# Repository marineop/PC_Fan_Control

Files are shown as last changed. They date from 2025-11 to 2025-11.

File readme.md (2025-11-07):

## Introduction
I have a PC fan that I removed from a CPU liquid cooler, and I'm powering it with a 12V power supply to use it for air filtration.  
However, when it's late at night, the fan's noise is a bit loud. But isn't this a PWM fan? I could use a development board to output a PWM signal and control the speed, but then I'd be short a development board.  
While searching online, I happened to come across a few useful online resources. I realized that in this day and age, this is actually possible to DIY a PCB board for simple device controls.  
* [Noctua PWM specifications white paper](https://cdn.noctua.at/media/Noctua_PWM_specifications_white_paper.pdf)
* [KiCad tutorial video from DigiKey](https://www.youtube.com/watch?v=vaCVh2SAZY4&list=PLEBQazB0HUyR24ckSZ5u05TZHV9khgA1O&index=1)
* [TI Power Dedigner](https://webench.ti.com/power-designer/)
* [OSH Park](https://oshpark.com/)
* [Mouser](https://www.mouser.com)

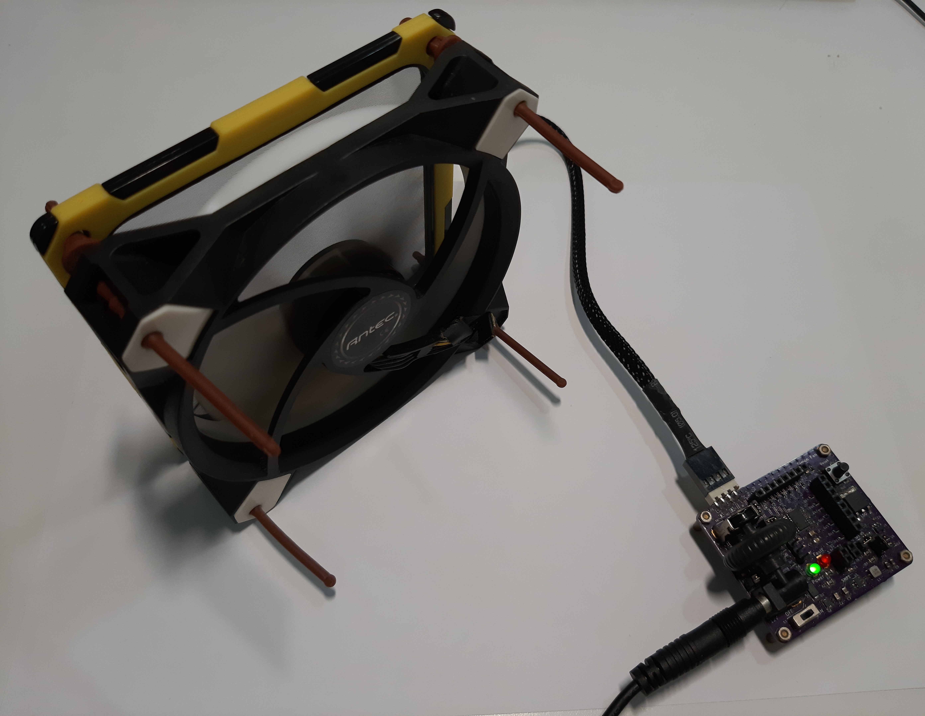
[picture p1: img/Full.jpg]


## Functionality

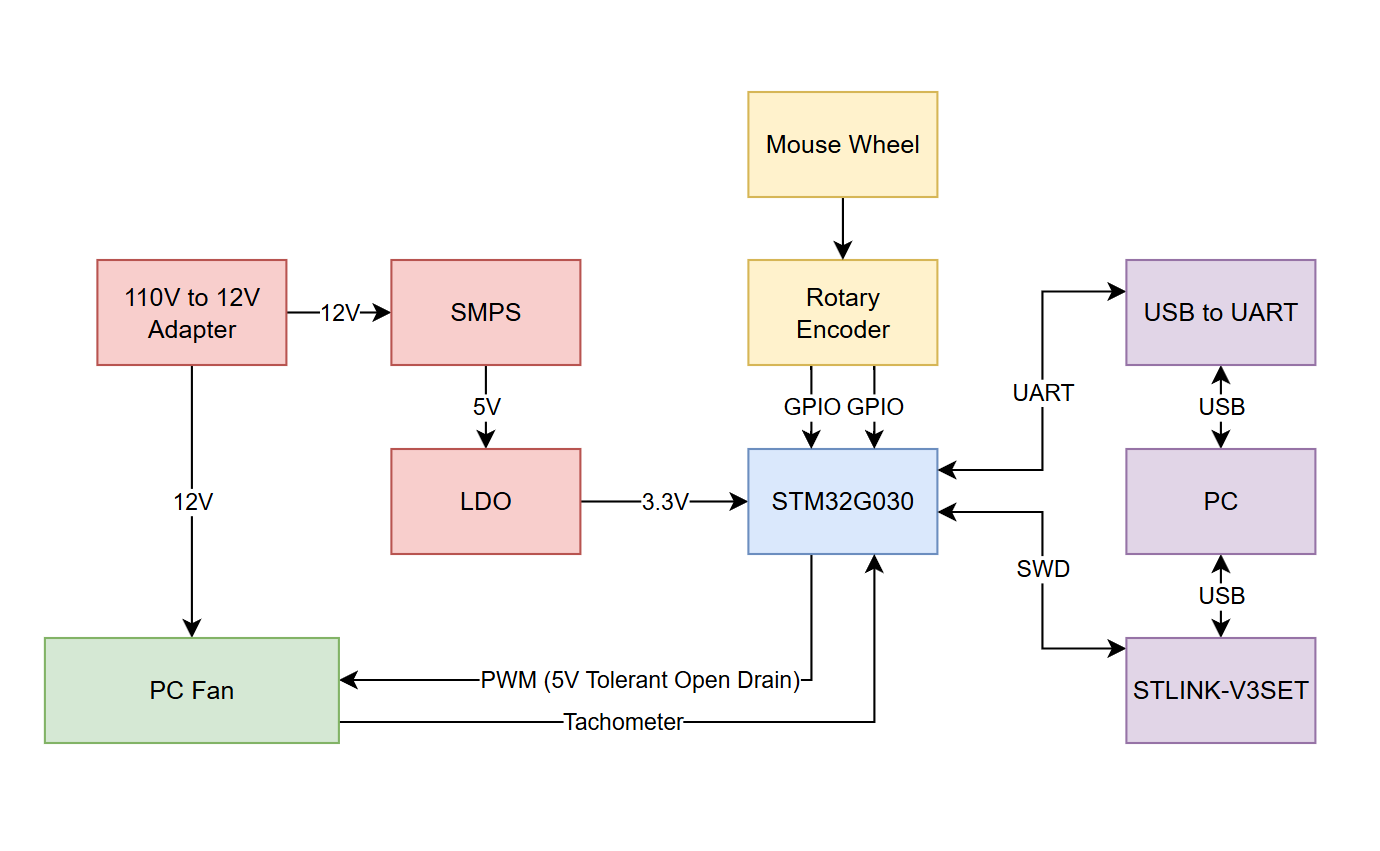
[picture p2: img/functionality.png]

## Schematic - KiCad, Ti Power Deisgner  
* [KiCad](https://www.kicad.org/)  
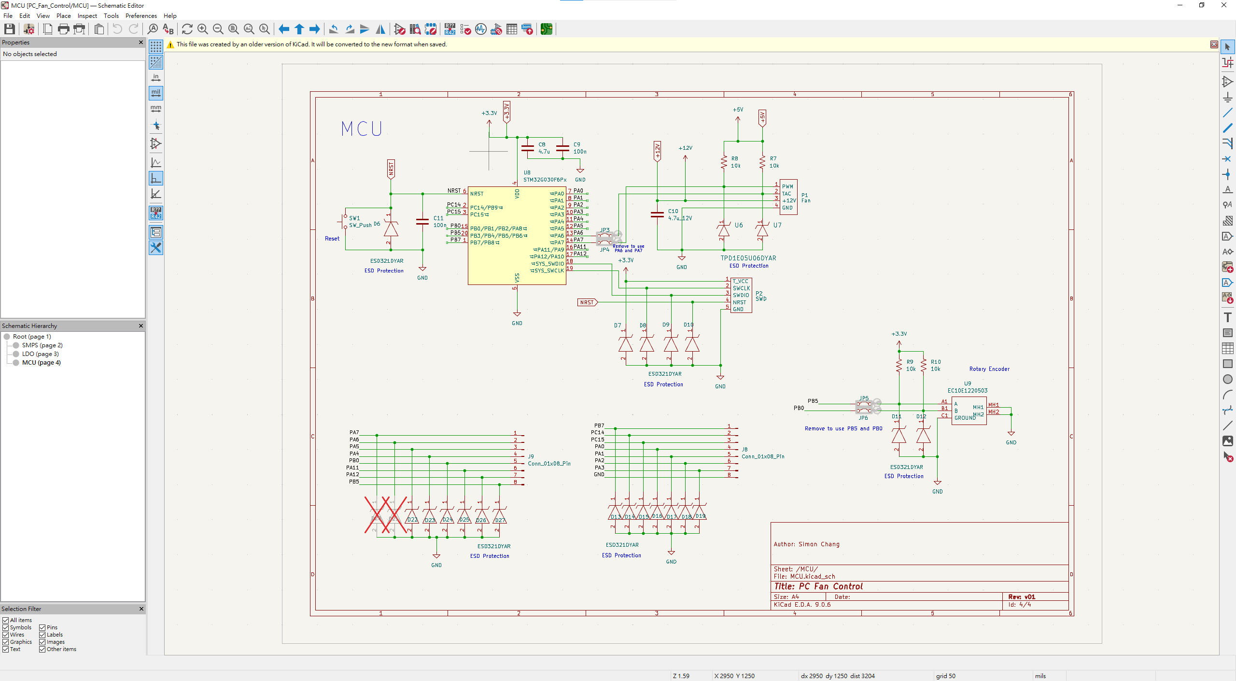
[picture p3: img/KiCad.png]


## PCB Layout - KiCad  
* Front side
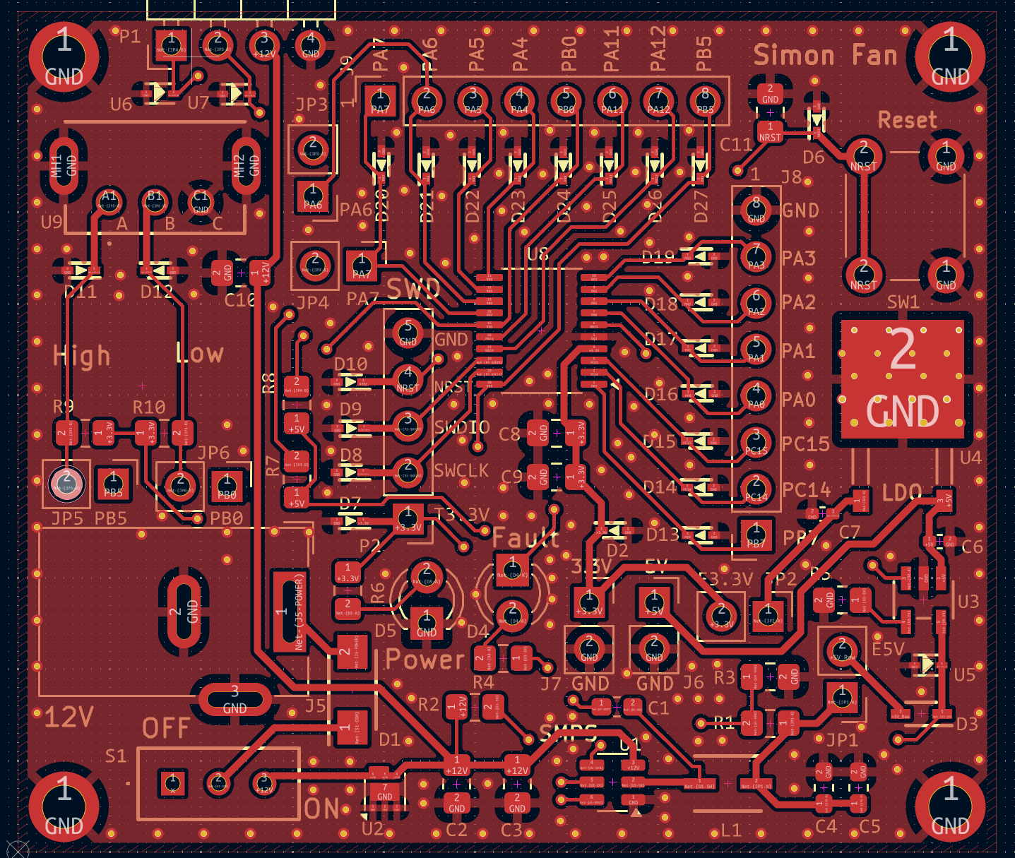
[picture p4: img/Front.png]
Front side

* Back side
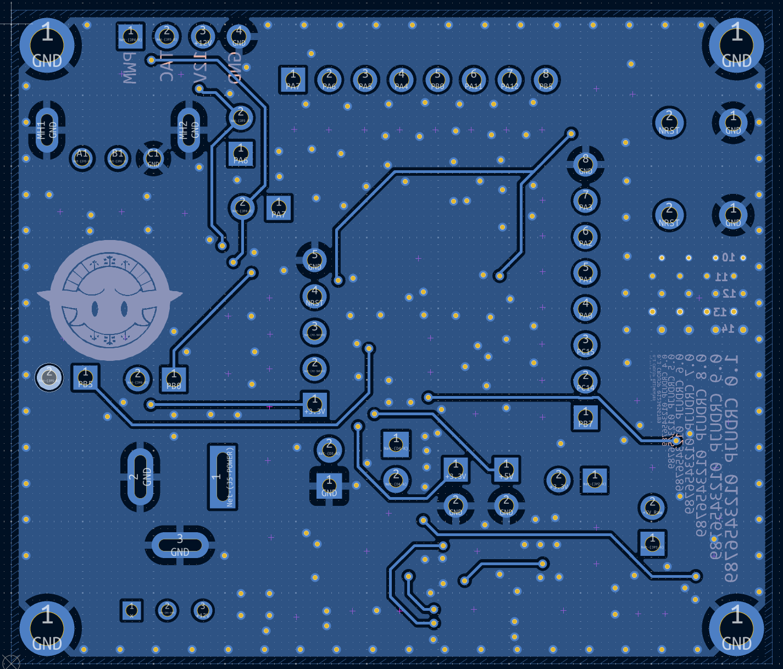
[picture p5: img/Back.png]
Back side


### PCB Fabrication - OSH Park  
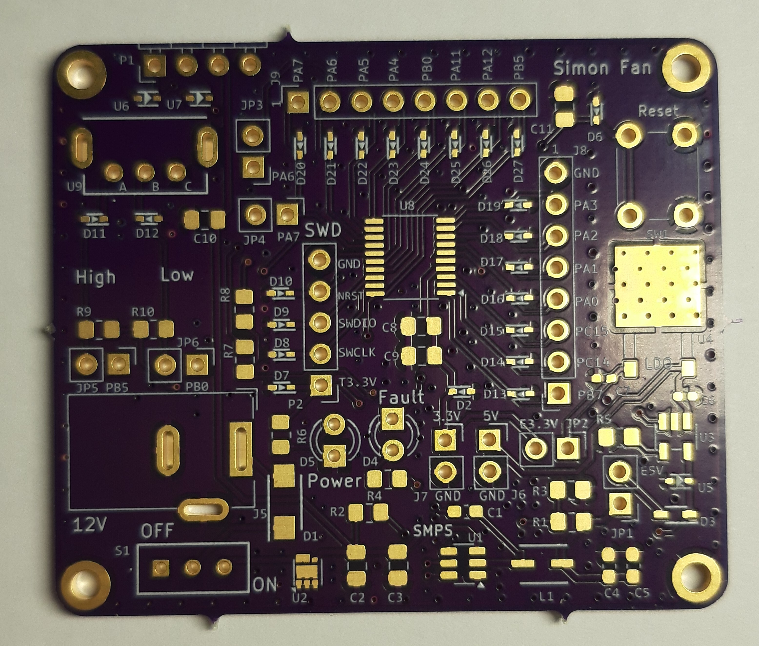
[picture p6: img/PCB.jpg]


### Order Components - Mouser  

### Solder  
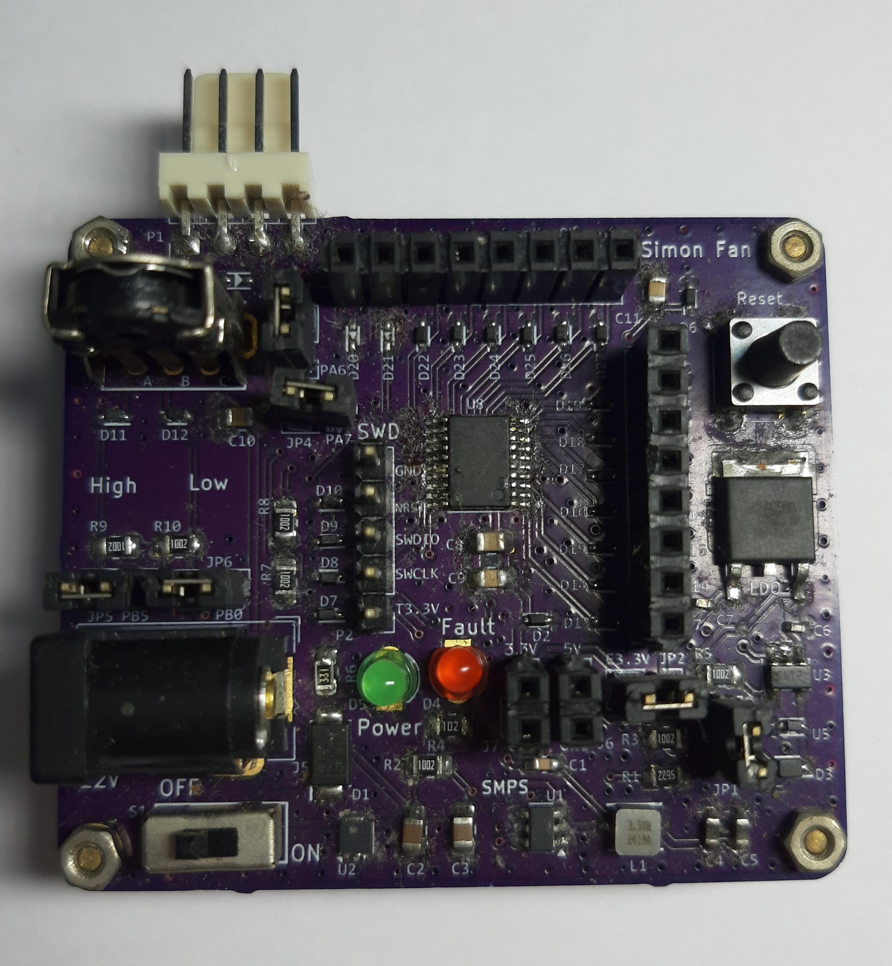
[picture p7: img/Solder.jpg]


### Firmware  
* Programmer: STLINK-V3SET
* IDE: STM32CubeIDE
* Pin Define
    * PA7: PWM, TIM14_CH1
    * PA6: tachometer, TIM16_CH1
    * PB0: Rotary Encoder A (DI)
    * PB5: Rotary Encoder B (DI)
    * PA2: USART_TX
    * PA3: USART_RX
* Rotary Encoder Debouncing
    * Use TIM3 to periodically record last 10 pin states
        * if current state is 0, and there are at least eight 1s in the history, then change state to 1
        * if current state is 1, and there are at least eight 0s in the history, then change state to 0
* Debug USART: 115200, N, 8, 1

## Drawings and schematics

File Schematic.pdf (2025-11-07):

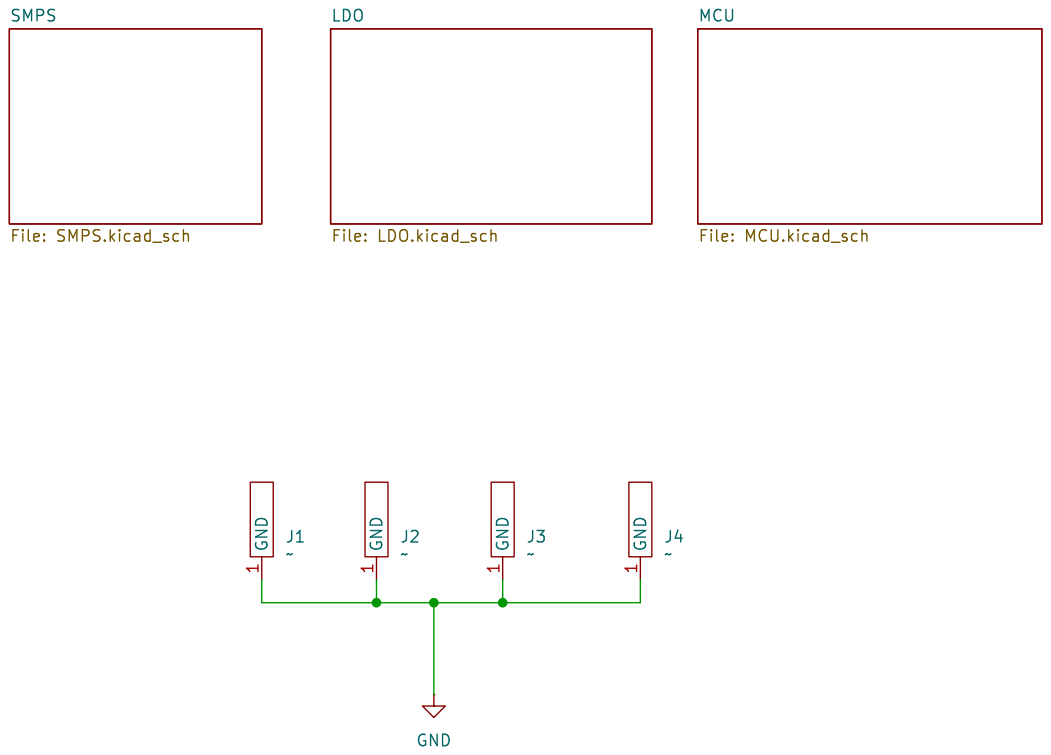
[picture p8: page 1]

Id: 1/4 Title: PC Fan Control File: PC_Fan_Control.kicad_sch Sheet: / Author: Simon Chang

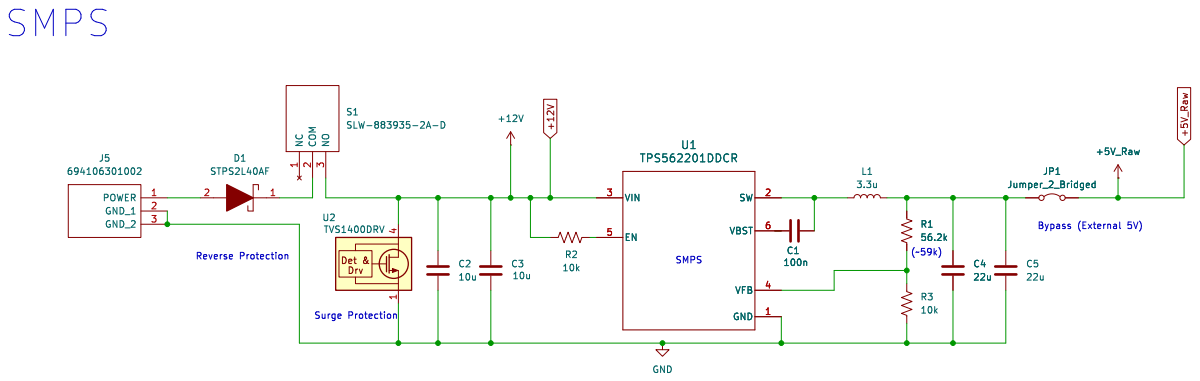
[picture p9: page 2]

Surge Protection Reverse Protection SMPS

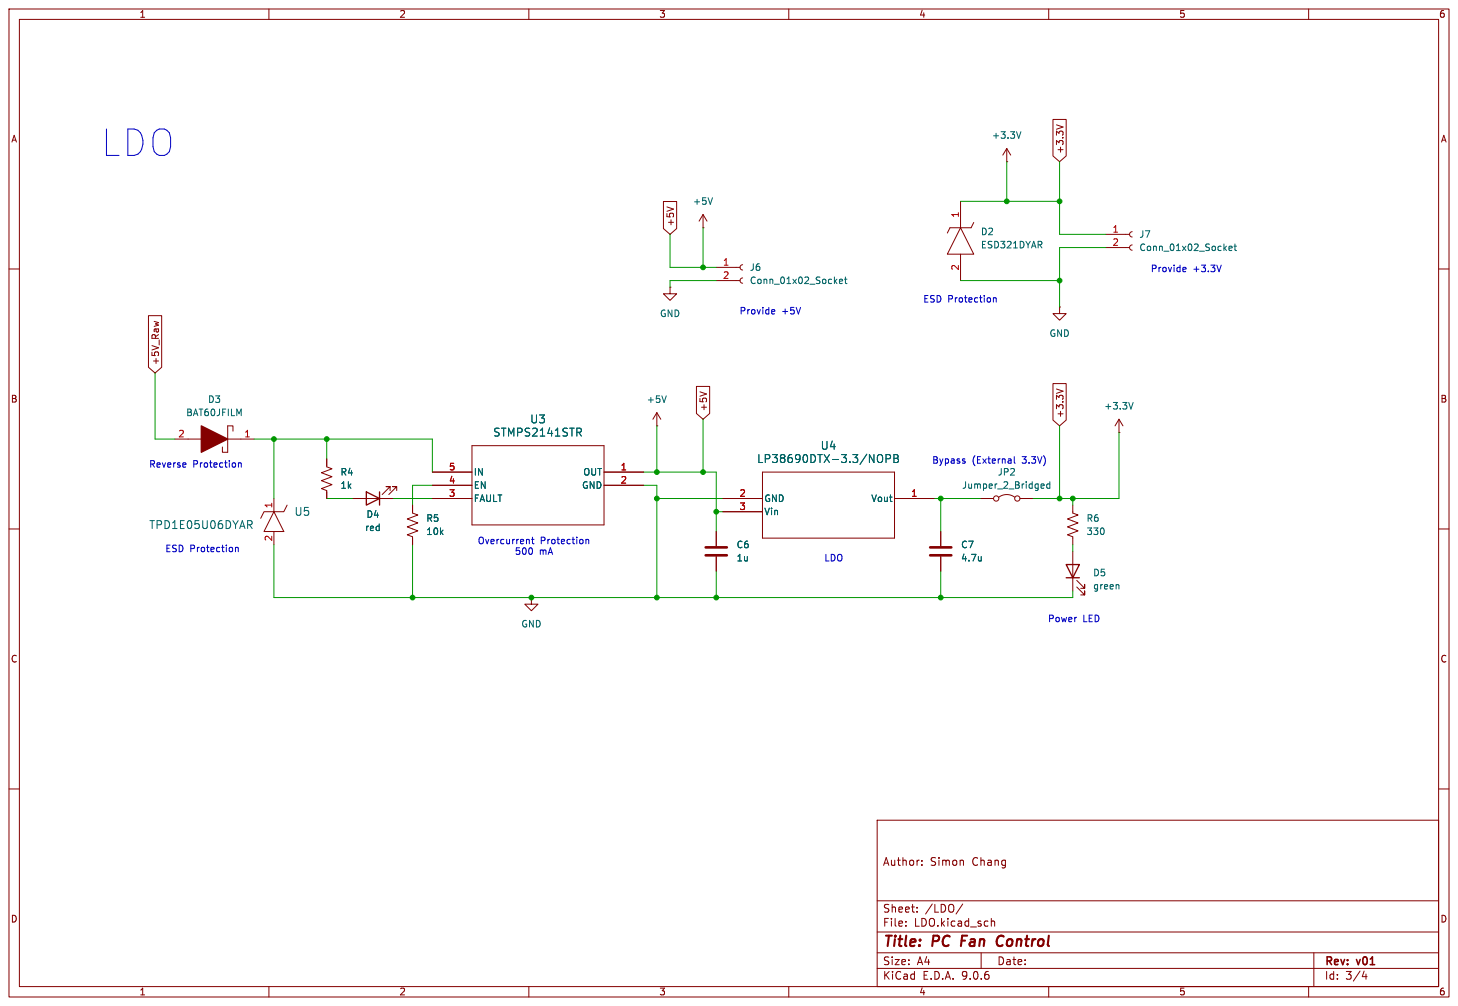
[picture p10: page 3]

Id: 3/4 Title: PC Fan Control File: LDO.kicad_sch Sheet: /LDO/ Author: Simon Chang R5

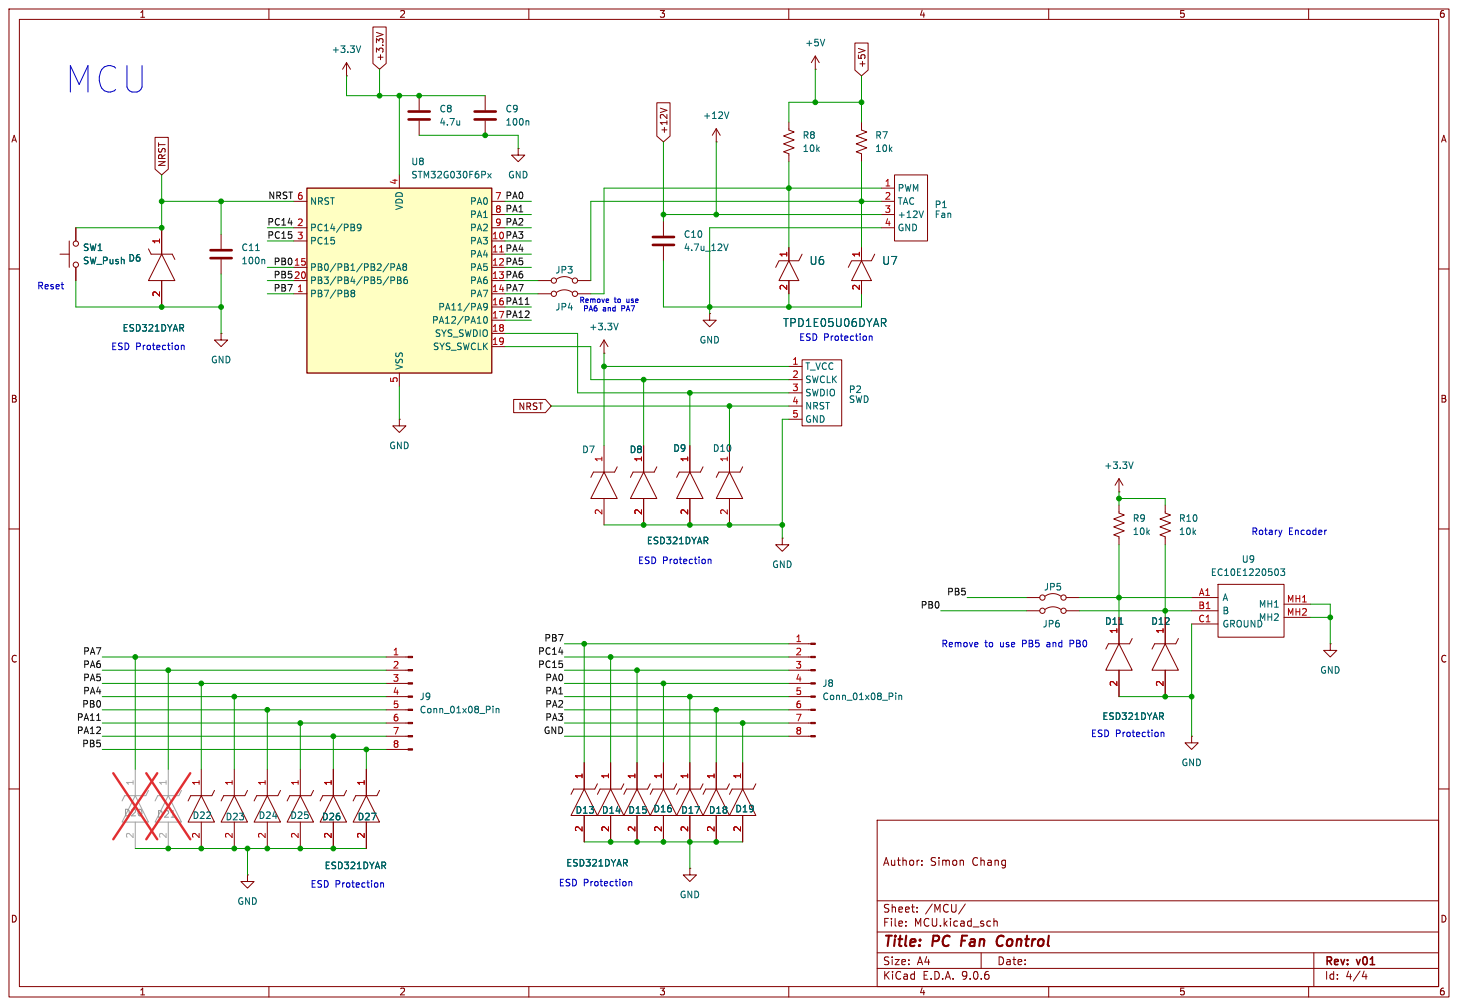
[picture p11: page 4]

Id: 4/4 Title: PC Fan Control File: MCU.kicad_sch Sheet: /MCU/ Author: Simon Chang

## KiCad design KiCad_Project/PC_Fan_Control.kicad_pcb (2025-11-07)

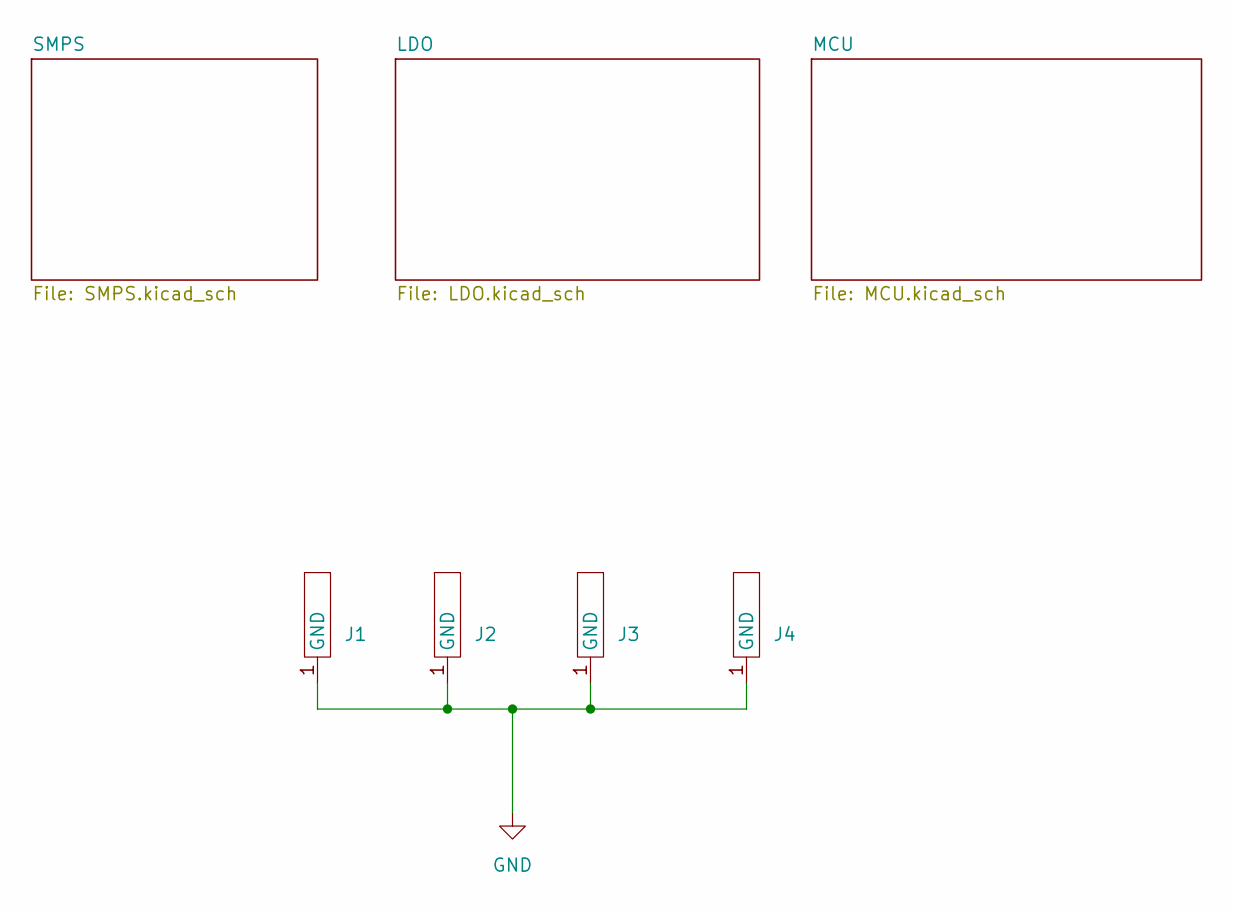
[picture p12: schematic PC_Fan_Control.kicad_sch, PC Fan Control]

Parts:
J1, J2, J3, J4: Standoff

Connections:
GND: J1.1 (GND), J2.1 (GND), J3.1 (GND), J4.1 (GND); also elsewhere on the board

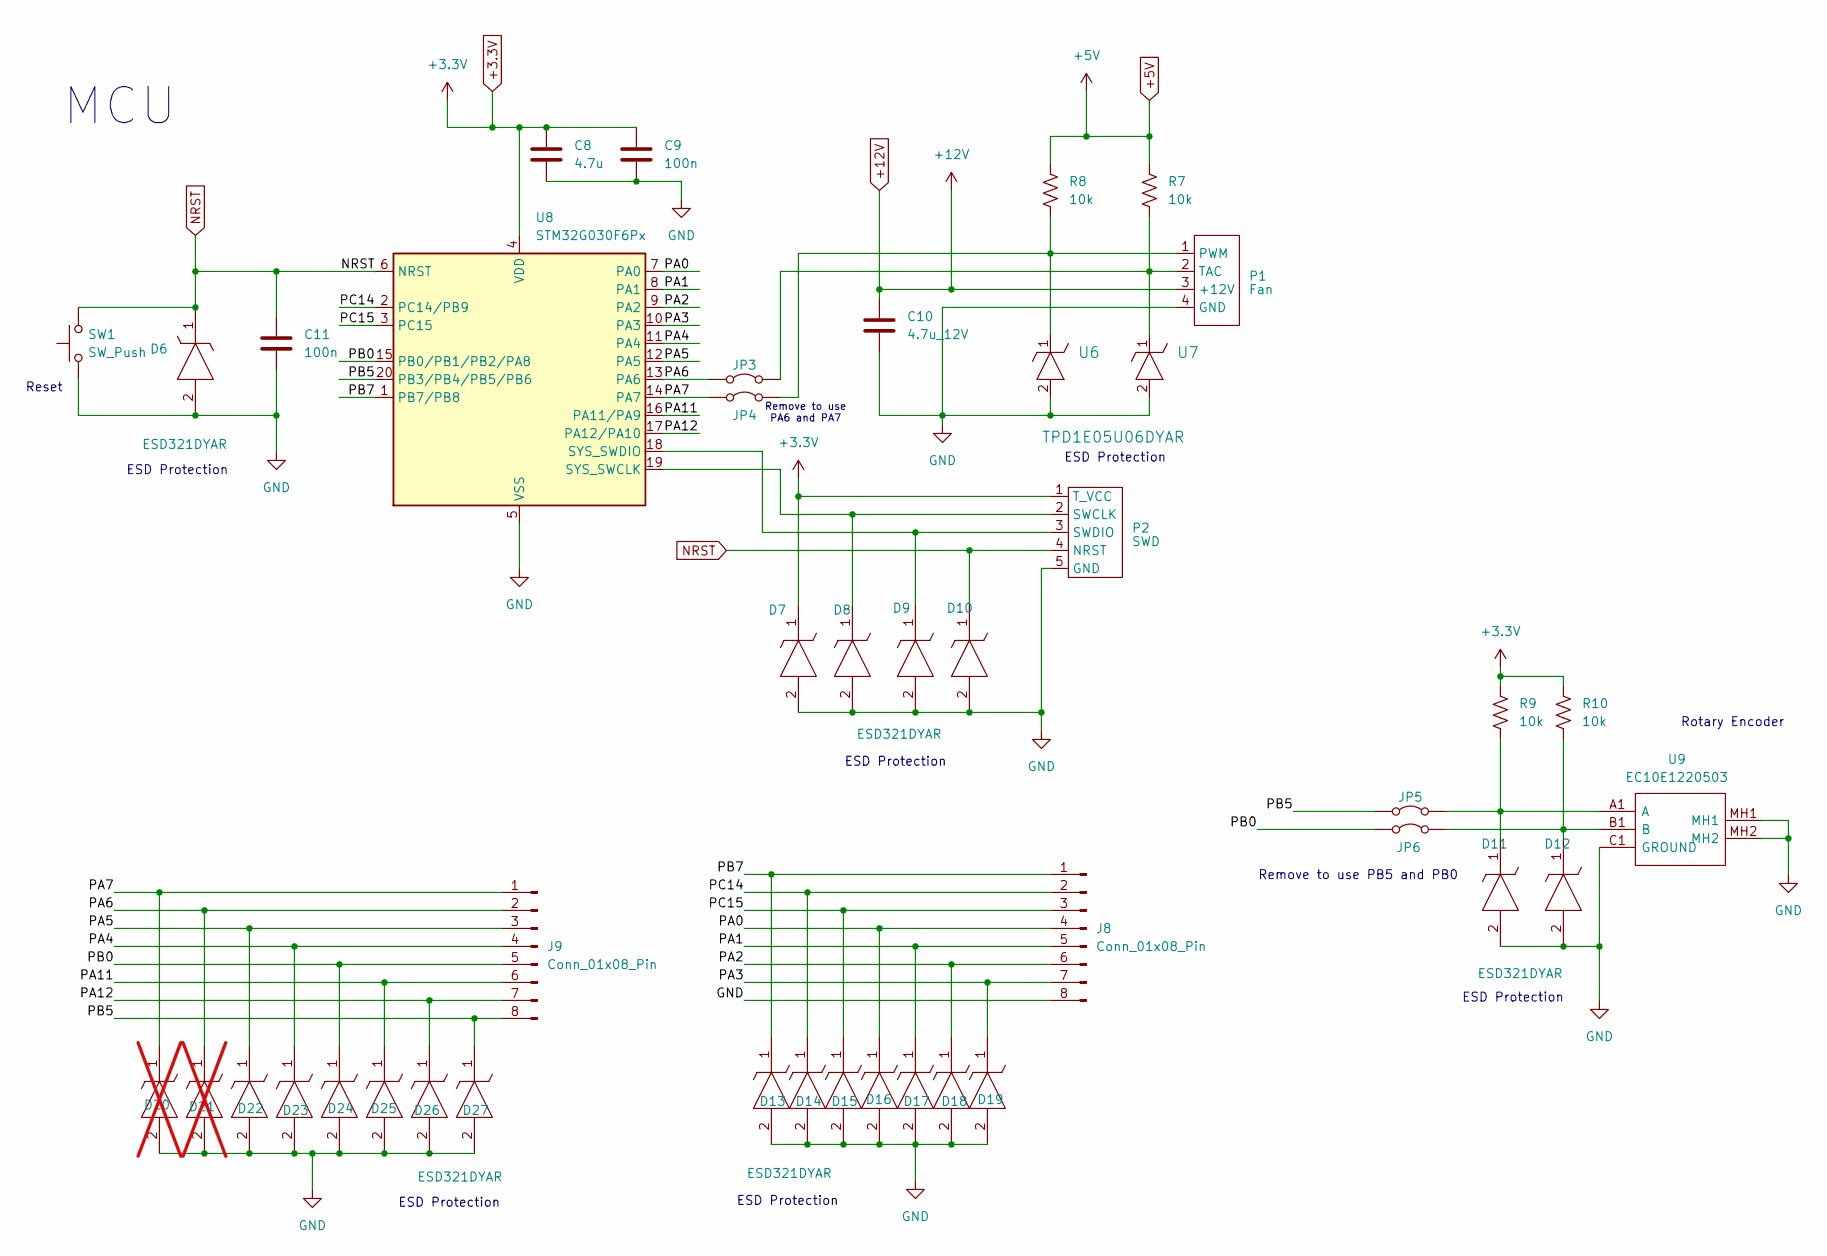
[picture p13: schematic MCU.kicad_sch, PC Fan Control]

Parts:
C8: 4.7u; C_0805_2012Metric_Pad1.18x1.45mm_HandSolder
C9, C11: 100n; C_0805_2012Metric_Pad1.18x1.45mm_HandSolder
C10: 4.7u_12V; C_0805_2012Metric_Pad1.18x1.45mm_HandSolder
D6, D7, D8, D9, D10, D11, D12, D13, D14, D15, D16, D17, D18, D19, D22, D23, D24, D25, D26, D27: ESD321DYAR; SOT (SOD-523)_Ti_DYA; Mouser Part Number 595-ESD321DYAR
D20, D21: ESD321DYAR; SOT (SOD-523)_Ti_DYA; Mouser Part Number 595-ESD321DYAR; not fitted
J8, J9: Conn_01x08_Pin; PinSocket_1x08_P2.54mm_Vertical
JP3, JP4, JP5, JP6: Jumper_2_Bridged; PinHeader_1x02_P2.54mm_Vertical
P1: Fan; PinHeader_1x04_P2.54mm_Horizontal
P2: SWD; PinHeader_1x05_P2.54mm_Vertical
R7, R8, R9, R10: 10k; R_0805_2012Metric_Pad1.20x1.40mm_HandSolder
SW1: SW_Push; SW_PUSH_6mm_H9.5mm
U6, U7: TPD1E05U06DYAR; SOT5x3_DYA_TEX
U8: STM32G030F6Px; TSSOP-20_4.4x6.5mm_P0.65mm
U9: EC10E1220503; Mouser Part Number 688-EC10E1220503

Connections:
+3.3V: C8.1, C9.1, D7.1, P2.1 (T_VCC), R9.1, R10.1, U8.4 (VDD); also elsewhere on the board
+5V: R7.1, R8.1; also elsewhere on the board
+12V: C10.1, P1.3 (+12V); also elsewhere on the board
/MCU/PA0: D16.1, J8.4, U8.7 (PA0)
/MCU/PA1: D17.1, J8.5, U8.8 (PA1)
/MCU/PA2: D18.1, J8.6, U8.9 (PA2)
/MCU/PA3: D19.1, J8.7, U8.10 (PA3)
/MCU/PA4: D23.1, J9.4, U8.11 (PA4)
/MCU/PA5: D22.1, J9.3, U8.12 (PA5)
/MCU/PA6: D21.1, J9.2, JP3.1 (A), U8.13 (PA6)
/MCU/PA7: D20.1, J9.1, JP4.1 (A), U8.14 (PA7)
/MCU/PA11: D25.1, J9.6, U8.16 (PA11/PA9)
/MCU/PA12: D26.1, J9.7, U8.17 (PA12/PA10)
/MCU/PB0: D24.1, J9.5, JP6.1 (A), U8.15 (PB0/PB1/PB2/PA8)
/MCU/PB5: D27.1, J9.8, JP5.1 (A), U8.20 (PB3/PB4/PB5/PB6)
/MCU/PB7: D13.1, J8.1, U8.1 (PB7/PB8)
/MCU/PC14: D14.1, J8.2, U8.2 (PC14/PB9)
/MCU/PC15: D15.1, J8.3, U8.3 (PC15)
GND: C8.2, C9.2, C10.2, C11.2, D6.2, D7.2, D8.2, D9.2, D10.2, D11.2, D12.2, D13.2, D14.2, D15.2, D16.2, D17.2, D18.2, D19.2, D20.2, D21.2, D22.2, D23.2, D24.2, D25.2, D26.2, D27.2, J8.8, P1.4 (GND), P2.5 (GND), SW1.1, U6.2, U7.2, U8.5 (VSS), U9.C1 (GROUND), U9.MH1, U9.MH2; also elsewhere on the board
NRST: C11.1, D6.1, D10.1, P2.4 (NRST), SW1.2, U8.6 (NRST)
unnamed: JP3.2 (B), P1.2 (TAC), R7.2, U7.1
unnamed: JP4.2 (B), P1.1 (PWM), R8.2, U6.1
unnamed: D11.1, JP5.2 (B), R9.2, U9.A1 (A)
unnamed: D12.1, JP6.2 (B), R10.2, U9.B1 (B)
unnamed: D8.1, P2.2 (SWCLK), U8.19 (SYS_SWCLK)
unnamed: D9.1, P2.3 (SWDIO), U8.18 (SYS_SWDIO)

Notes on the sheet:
ESD Protection
Remove to use PA6 and PA7
Rotary Encoder
MCU
Remove to use PB5 and PB0
Reset

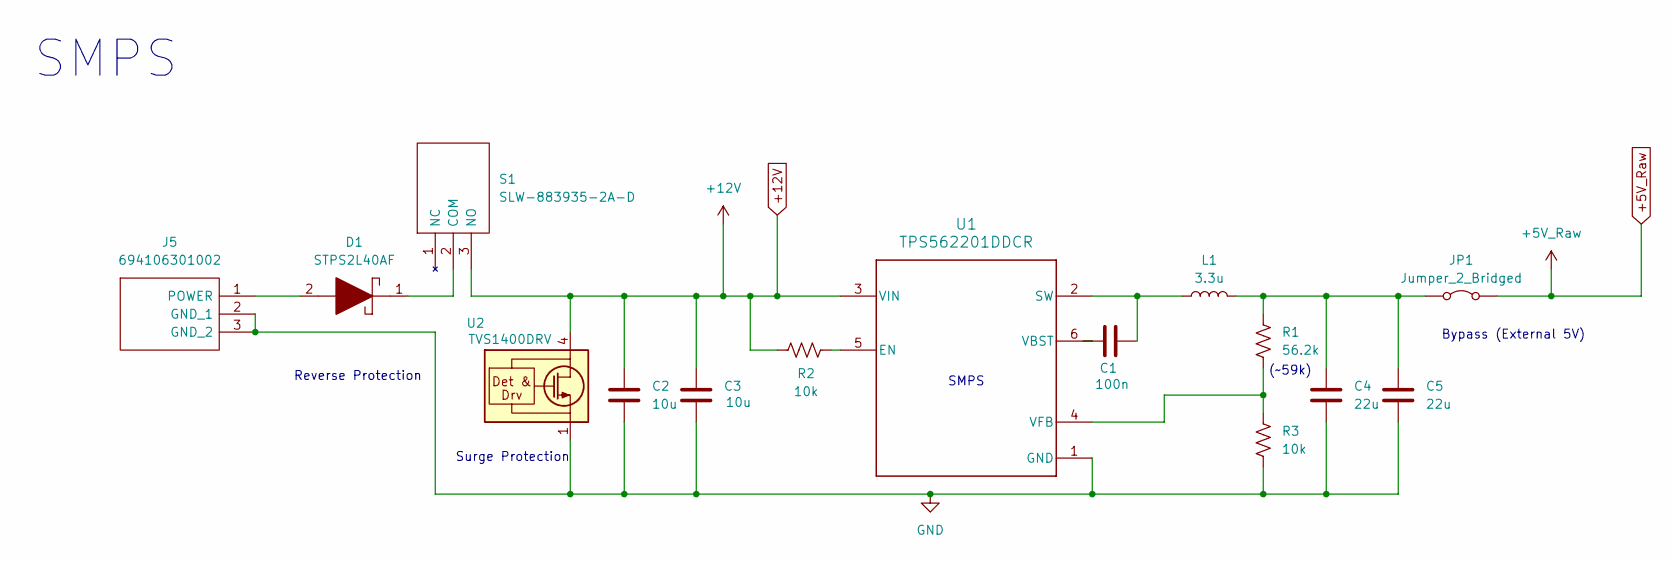
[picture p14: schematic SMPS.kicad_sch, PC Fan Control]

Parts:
C1: 100n; C_0603_1608Metric_Pad1.08x0.95mm_HandSolder
C2, C3: 10u; C_0805_2012Metric_Pad1.18x1.45mm_HandSolder
C4, C5: 22u; C_0603_1608Metric_Pad1.08x0.95mm_HandSolder
D1: STPS2L40AF; SODFL5226X110N; Mouser Part Number 511-STPS2L40AF
J5: 694106301002; BarrelJack_Wuerth_6941xx301002; Mouser Part Number 710-694106301002
JP1: Jumper_2_Bridged; PinHeader_1x02_P2.54mm_Vertical
L1: 3.3u; IHLP1212BZER3R3M11
R1: 56.2k; R_0805_2012Metric_Pad1.20x1.40mm_HandSolder
R2, R3: 10k; R_0805_2012Metric_Pad1.20x1.40mm_HandSolder
S1: SLW-883935-2A-D; SLW8839352AD; Mouser Part Number 179-SLW-883935-2A-D
U1: TPS562201DDCR; TSOT-23-6
U2: TVS1400DRV; WSON-6-1EP_2x2mm_P0.65mm_EP1x1.6mm

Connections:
+5V_Raw: JP1.2 (B); also elsewhere on the board
+12V: C2.1, C3.1, R2.1, S1.3 (NO), U1.3 (VIN), U2.4 (IN), U2.5 (IN), U2.6 (IN); also elsewhere on the board
GND: C2.2, C3.2, C4.2, C5.2, J5.2 (GND_1), J5.3 (GND_2), R3.2, U1.1 (GND), U2.1 (GND), U2.2 (GND), U2.3 (GND), U2.7 (GND); also elsewhere on the board
unnamed: D1.2, J5.1 (POWER)
unnamed: C4.1, C5.1, JP1.1 (A), L1.2, R1.1
unnamed: D1.1, S1.2 (COM)
unnamed: R2.2, U1.5 (EN)
unnamed: C1.2, L1.1, U1.2 (SW)
unnamed: C1.1, U1.6 (VBST)
unnamed: R1.2, R3.1, U1.4 (VFB)

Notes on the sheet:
Surge Protection
Reverse Protection
SMPS
Bypass (External 5V)
(~59k)

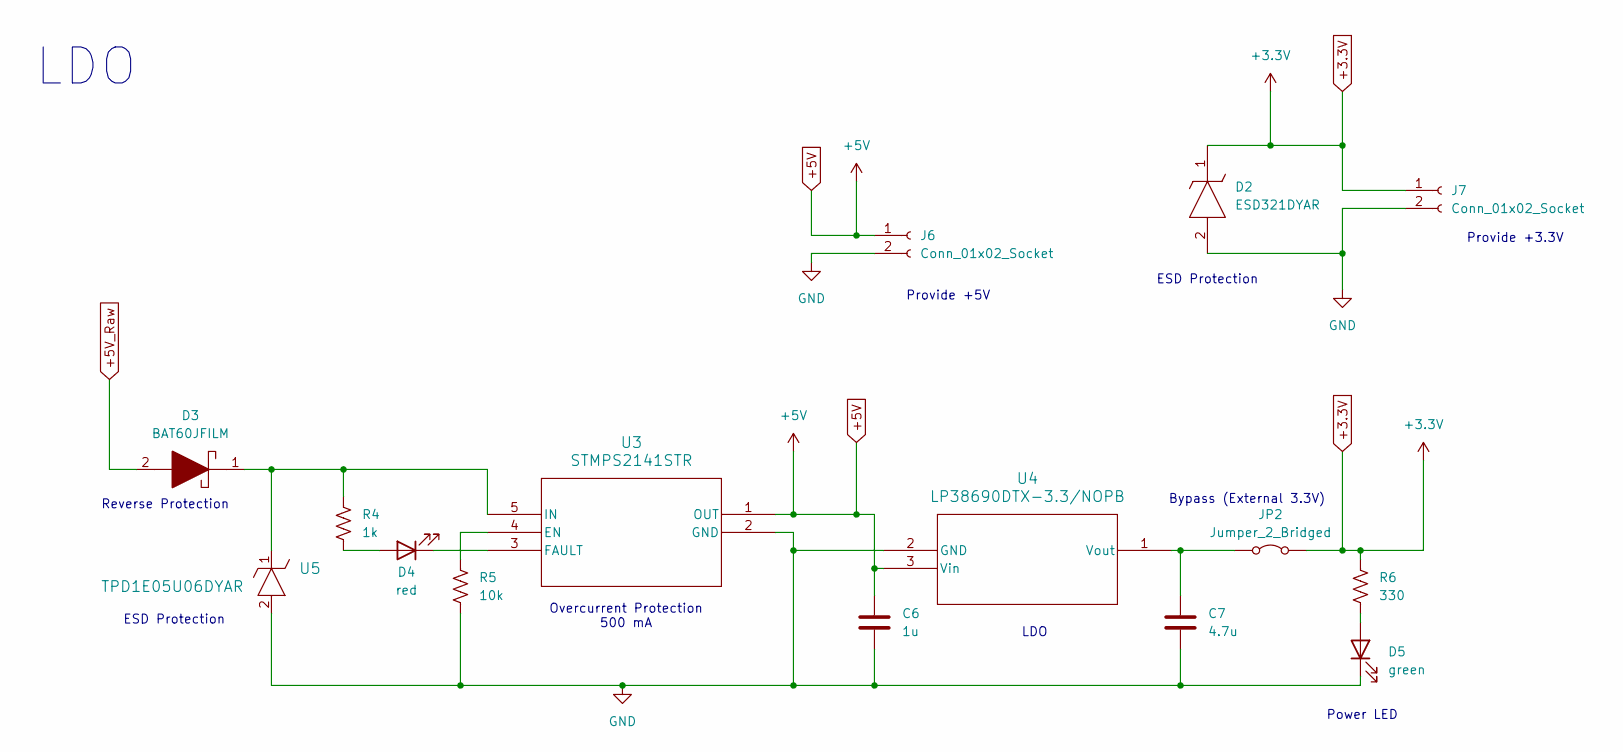
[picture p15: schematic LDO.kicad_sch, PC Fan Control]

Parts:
C6: 1u; C_0402_1005Metric_Pad0.74x0.62mm_HandSolder
C7: 4.7u; C_0402_1005Metric_Pad0.74x0.62mm_HandSolder
D2: ESD321DYAR; SOT (SOD-523)_Ti_DYA; Mouser Part Number 595-ESD321DYAR
D3: BAT60JFILM; SOD2513X117N; Mouser Part Number 511-BAT60JFILM
D4: red; LED_D3.0mm
D5: green; LED_D3.0mm
J6, J7: Conn_01x02_Socket; PinSocket_1x02_P2.54mm_Vertical
JP2: Jumper_2_Bridged; PinHeader_1x02_P2.54mm_Vertical
R4: 1k; R_0805_2012Metric_Pad1.20x1.40mm_HandSolder
R5: 10k; R_0805_2012Metric_Pad1.20x1.40mm_HandSolder
R6: 330; R_0805_2012Metric_Pad1.20x1.40mm_HandSolder
U3: STMPS2141STR; SOT23-5L_STM
U4: LP38690DTX-3.3/NOPB; TO252-3
U5: TPD1E05U06DYAR; SOT5x3_DYA_TEX

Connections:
+3.3V: D2.1, J7.1, JP2.2 (B), R6.1; also elsewhere on the board
+5V: C6.1, J6.1, U3.1 (OUT), U4.3 (Vin); also elsewhere on the board
+5V_Raw: D3.2; also elsewhere on the board
GND: C6.2, C7.2, D2.2, D5.1 (K), J6.2, J7.2, R5.2, U3.2 (GND), U4.2 (GND), U5.2; also elsewhere on the board
unnamed: D4.2 (A), R4.2
unnamed: D4.1 (K), U3.3 (FAULT)
unnamed: D5.2 (A), R6.2
unnamed: C7.1, JP2.1 (A), U4.1 (Vout)
unnamed: R5.1, U3.4 (EN)
unnamed: D3.1, R4.1, U3.5 (IN), U5.1

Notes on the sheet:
Power LED
Overcurrent Protection 500 mA
ESD Protection
Reverse Protection
Provide +5V
Provide +3.3V
Bypass (External 3.3V)
LDO

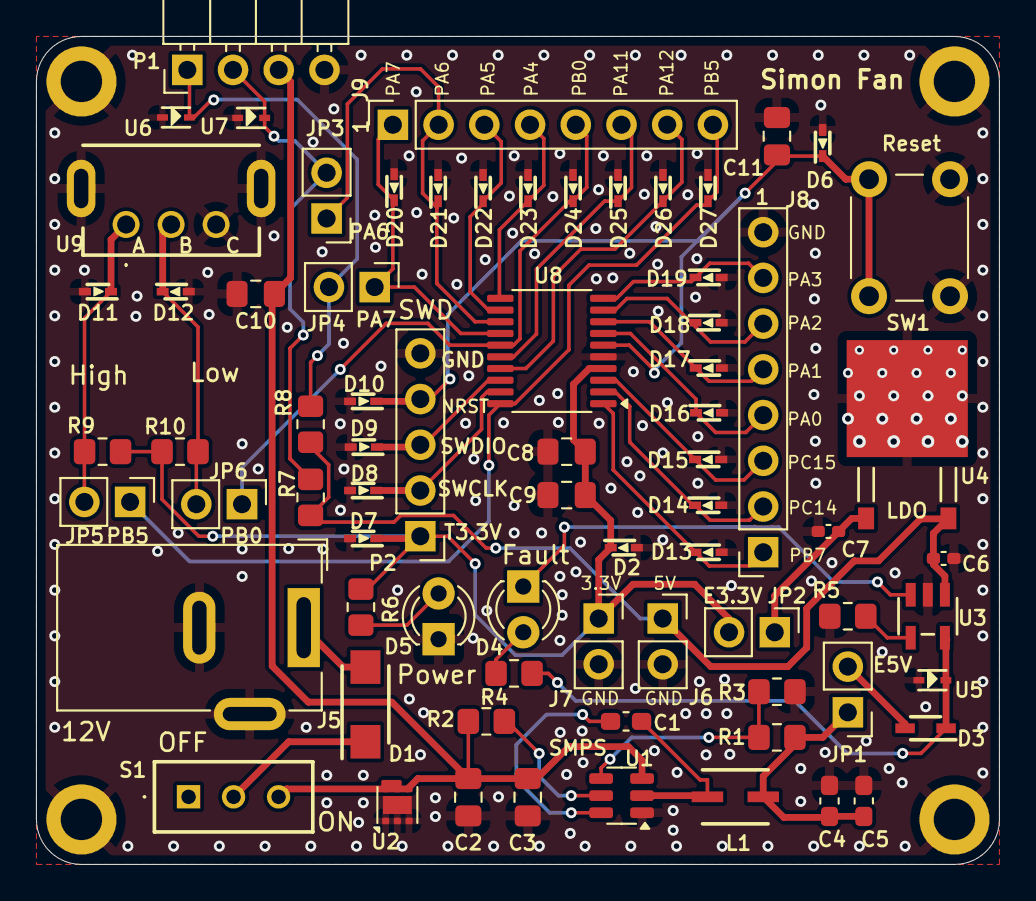
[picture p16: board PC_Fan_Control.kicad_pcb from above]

Board: 2 copper layers, 53.5 x 46.0 mm, 77 parts (0 on the bottom side), 40 nets.

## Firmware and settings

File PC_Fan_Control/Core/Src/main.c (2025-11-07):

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
/* Includes ------------------------------------------------------------------*/
#include "main.h"

/* USER CODE BEGIN Includes */
#include <stdbool.h>
#include <stdio.h>
#include <string.h>
/* USER CODE END Includes */

/* USER CODE BEGIN PM */

#define PWM_INCREMENT				(10)
#define PWM_MAX_DUTY_CYCLE			(1000)
#define PRINT_RPM_INTERVAL			(200)			// ms
#define MAX_DEBOUNCING_COUNTER		(10)			// 0.1 ms x 10 = 1 ms
#define MIN_DEBOUNCING_COUNTER		(0)

#define DEBOUNCING_SET_BIT_MASK		(0x200)
#define DEBOUNCING_MASK				(0x3FF)
#define DEBOUNCING_TOTAL			(10)
#define DEBOUNCING_THRESHOLD		(8)
/* USER CODE END PM */

TIM_HandleTypeDef htim3;
TIM_HandleTypeDef htim14;
TIM_HandleTypeDef htim16;

UART_HandleTypeDef huart2;

/* USER CODE BEGIN PV */

volatile GPIO_PinState pb0Old = GPIO_PIN_RESET;
volatile GPIO_PinState pb5Old = GPIO_PIN_RESET;

uint32_t pb0History = 0;
uint32_t pb5History = 0;

volatile int32_t dutyCycle = 1000;

volatile bool captured = false;
volatile uint32_t lastCaptureValue = 0;
volatile uint32_t captureValue = 0;

volatile int64_t timeStamp;
int64_t lastPrintTime = 0;

/* USER CODE END PV */

void SystemClock_Config(void);
static void MX_GPIO_Init(void);
static void MX_TIM3_Init(void);
static void MX_TIM14_Init(void);
static void MX_TIM16_Init(void);
static void MX_USART2_UART_Init(void);
/* USER CODE BEGIN PFP */

void UpdateSpeed(GPIO_PinState aLast, GPIO_PinState bLast, GPIO_PinState aNew, GPIO_PinState bNew);

/* USER CODE END PFP */

/* USER CODE BEGIN 0 */
int __io_putchar(int ch)
{
	HAL_UART_Transmit(&huart2, (uint8_t*) &ch, 1, 0xFFFF);
	return ch;
}

void HAL_TIM_IC_CaptureCallback(TIM_HandleTypeDef *htim)
{
	if (htim == &htim16)
	{
		lastCaptureValue = captureValue;
		captureValue = htim16.Instance->CCR1;
		captured = true;
	}
}

uint32_t UpdatePinHistory(uint32_t history, GPIO_PinState newState)
{
	history >>= 1;
	if(newState == GPIO_PIN_RESET)
	{
		history |= DEBOUNCING_SET_BIT_MASK;
	}
	else
	{
		history &= (~DEBOUNCING_SET_BIT_MASK);
	}

	history &= DEBOUNCING_MASK;

	return history;
}

GPIO_PinState CheckStateChange(GPIO_PinState currentState, uint32_t history)
{
	GPIO_PinState newState;

	if(currentState == GPIO_PIN_RESET)
	{
		if(__builtin_popcount(history) >= DEBOUNCING_THRESHOLD)
		{
			newState = GPIO_PIN_SET;
		}

	}
	else
	{
		if(__builtin_popcount(history) <= (DEBOUNCING_TOTAL - DEBOUNCING_THRESHOLD))
		{
			newState = GPIO_PIN_RESET;
		}
	}

	return newState;
}

void HAL_TIM_PeriodElapsedCallback(TIM_HandleTypeDef *htim)
{
	if (htim == &htim3)
	{
		GPIO_PinState pb0Current = HAL_GPIO_ReadPin(GPIOB, GPIO_PIN_0);
		GPIO_PinState pb5Current = HAL_GPIO_ReadPin(GPIOB, GPIO_PIN_5);

		pb0History = UpdatePinHistory(pb0History, pb0Current);
		pb5History = UpdatePinHistory(pb5History, pb5Current);

		GPIO_PinState pb0New = CheckStateChange(pb0Current, pb0History);
		GPIO_PinState pb5New = CheckStateChange(pb5Current, pb5History);;

		if(pb0Old != pb0New || pb5Old != pb5New)
		{
			UpdateSpeed(pb0Old, pb5Old, pb0New, pb5New);

			pb0Old = pb0New;
			pb5Old = pb5New;
		}
	}
}

void UpdateSpeed(GPIO_PinState aLast, GPIO_PinState bLast, GPIO_PinState aNew, GPIO_PinState bNew)
{
	int32_t direction = 0;

	if (aLast == GPIO_PIN_RESET) // 0
	{
		if (bLast == GPIO_PIN_RESET) // 0
		{
			if (aNew == GPIO_PIN_RESET) // 0
			{
				if (bNew == GPIO_PIN_RESET)
				{
				}
				else // 1
				{
					direction = -1; // 0 0 0 1
				}
			}
			else // 1
			{
				if (bNew == GPIO_PIN_RESET) // 0
				{
					direction = 1; // 0 0 1 0
				}
				else
				{
				}
			}
		}
		else // 1
		{
			if (aNew == GPIO_PIN_RESET) // 0
			{
				if (bNew == GPIO_PIN_RESET) // 0
				{
					direction = 1; // 0 1 0 0
				}
				else
				{
				}
			}
			else
			{
				if (bNew == GPIO_PIN_RESET)
				{
				}
				else
				{
					direction = -1; // 0 1 1 1
				}
			}
		}
	}
	else // 1
	{
		if (bLast == GPIO_PIN_RESET) // 0
		{
			if (aNew == GPIO_PIN_RESET) // 0
			{
				if (bNew == GPIO_PIN_RESET)
				{
					direction = -1; // 1 0 0 0
				}
				else
				{
				}
			}
			else // 1
			{
				if (bNew == GPIO_PIN_RESET) // 0
				{
				}
				else
				{
					direction = 1; // 1 0 1 1
				}
			}
		}
		else // 1
		{
			if (aNew == GPIO_PIN_RESET) // 0
			{
				if (bNew == GPIO_PIN_RESET) // 0
				{
				}
				else
				{
					direction = 1; // 1 1 0 1
				}
			}
			else
			{
				if (bNew == GPIO_PIN_RESET)
				{
					direction = -1; // 1 1 1 0
				}
				else
				{
				}
			}
		}
	}

	if (direction > 0)
	{
		dutyCycle += PWM_INCREMENT;
		if (dutyCycle > PWM_MAX_DUTY_CYCLE)
		{
			dutyCycle = PWM_MAX_DUTY_CYCLE;
		}

		htim14.Instance->CCR1 = dutyCycle;
	}
	else if (direction < 0)
	{
		dutyCycle -= PWM_INCREMENT;
		if (dutyCycle < 0)
		{
			dutyCycle = 0;
		}

		htim14.Instance->CCR1 = dutyCycle;
	}
}

/* USER CODE END 0 */

/**
  * @brief  The application entry point.
  * @retval int
  */
int main(void)
{

  /* MCU Configuration--------------------------------------------------------*/

  /* Reset of all peripherals, Initializes the Flash interface and the Systick. */
  HAL_Init();

  /* Configure the system clock */
  SystemClock_Config();

  /* Initialize all configured peripherals */
  MX_GPIO_Init();
  MX_TIM3_Init();
  MX_TIM14_Init();
  MX_TIM16_Init();
  MX_USART2_UART_Init();
  /* USER CODE BEGIN 2 */

	pb0Old = HAL_GPIO_ReadPin(GPIOB, GPIO_PIN_0);
	pb5Old = HAL_GPIO_ReadPin(GPIOB, GPIO_PIN_5);

	if(pb0Old == GPIO_PIN_SET)
	{
		pb0History = DEBOUNCING_MASK;
	}

	if(pb5Old == GPIO_PIN_SET)
	{
		pb5History = DEBOUNCING_MASK;
	}

	HAL_TIM_PWM_Start(&htim14, TIM_CHANNEL_1); // Fan PWM
	HAL_TIM_IC_Start_IT(&htim16, TIM_CHANNEL_1); // Tachometer PA6
	HAL_TIM_Base_Start_IT(&htim3); // Encoder PB0, PB5

  /* USER CODE END 2 */

  /* Infinite loop */
  /* USER CODE BEGIN WHILE */
	while (1)
	{
		if (captured)
		{
			captured = false;

			if (timeStamp - lastPrintTime > PRINT_RPM_INTERVAL)
			{
				lastPrintTime = timeStamp;

				int32_t diff = (int32_t)captureValue - (int32_t)lastCaptureValue;
				if (diff < 0)
				{
					diff += 65536;
				}

				int32_t rpm = (60 / 2 * 10000) / diff;

				printf("RPM: %ld, dutyCycle: %ld\r\n", rpm, dutyCycle);
			}
		}
    /* USER CODE END WHILE */

    /* USER CODE BEGIN 3 */
	}
  /* USER CODE END 3 */
}

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


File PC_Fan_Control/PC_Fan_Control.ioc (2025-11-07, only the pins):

Mcu.UserName=STM32G030F6Px
PA13.Signal=SYS_SWDIO
PA14-BOOT0.Signal=SYS_SWCLK
PA2.Signal=USART2_TX
PA3.Signal=USART2_RX
PA6.GPIO_Label=TIM16_CH1_TAC
PA6.Signal=S_TIM16_CH1
PA7.GPIO_Label=PWM
PA7.Signal=S_TIM14_CH1
PB0.GPIO_Label=Encoder
PB0.Signal=S_TIM3_CH3
PB5.GPIO_Label=Encoder
PB5.Signal=S_TIM3_CH2

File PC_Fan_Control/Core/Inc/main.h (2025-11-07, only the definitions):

#define TIM16_CH1_TAC_Pin GPIO_PIN_6
#define TIM16_CH1_TAC_GPIO_Port GPIOA
#define PWM_Pin GPIO_PIN_7
#define PWM_GPIO_Port GPIOA
#define Encoder_Pin GPIO_PIN_0
#define Encoder_GPIO_Port GPIOB
#define EncoderB5_Pin GPIO_PIN_5
#define EncoderB5_GPIO_Port GPIOB

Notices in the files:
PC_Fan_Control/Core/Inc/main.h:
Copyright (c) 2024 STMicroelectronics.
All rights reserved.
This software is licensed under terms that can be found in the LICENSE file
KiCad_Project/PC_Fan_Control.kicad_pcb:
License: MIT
